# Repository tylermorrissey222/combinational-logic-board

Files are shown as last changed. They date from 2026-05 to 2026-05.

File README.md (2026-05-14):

# Combinational Logic Board

### IECE 442 — Systems Analysis & Design

**Created by Tyler Morrissey**

-----

## Overview

An educational RFID based logic gate simulator that allows
students to physically place gate tokens on RFID readers to
build and simulate combinational logic circuits in real time.

The system evaluates a 5 gate combinational circuit, displays
a live schematic with wire states, generates the Boolean
expression, and shows a truth table with the active input
row highlighted.

-----

## Hardware

### Version 1 & 1.5

- Raspberry Pi 3B — display and GPIO switches
- Arduino Mega — 5x RC522 RFID readers
- Custom PCB bus board (KiCad)
- 5x RC522 RFID readers
- 4x input switches
- Sotsu FlipAction Go 14” display

### Version 2 (in development)

- Raspberry Pi CM5 — display
- Raspberry Pi Pico 2 — RFID readers and switches
- Custom PCB with integrated Pico socket (KiCad)

-----

## Supported Gate Types

|Gate|Symbol|
|----|---|
|AND |A·B |
|OR  |A+B |
|XOR |A⊕B |
|NAND|(A·B)’|
|NOR |(A+B)’|
|XNOR|(A⊕B)’|

-----

## Features

- Real time circuit simulation
- Live truth table with active row highlight
- Boolean expression generation
- Full adder auto detection mode
- Scalable pygame display (SCALE variable)
- Arduino/Pico handles RFID over Serial to Pi

-----

## Circuit Netlist

```
Slot 1: A, B     → Gate 1 output
Slot 2: B, C     → Gate 2 output
Slot 3: G1, G2   → Gate 3 output
Slot 4: G2, D    → Gate 4 output
Slot 5: G3, G4   → Final output Y
```

-----

## Files

### Code

|File |Description |
|---|---|
|code/arduino_rfid.ino |Arduino RFID reader sketch |
|code/combinational_logic.py |Pi display script |
|code/display_test_mac.py |Mac simulation (no hardware needed)|

### PCB

|Folder |Description |
|---|---|
|pcb/v1/ |V1 bus board — Arduino to RC522 |
|pcb/v2_pico/|V2 Pico board — integrated Pico socket|

-----

## Setup

### Hardware Setup

1. Connect Arduino Mega to Pi via USB
1. Wire 5x RC522 readers to Arduino per wiring guide
1. Wire 4x switches to Pi GPIO
1. Connect display via HDMI

### Software Setup

```bash
# On Raspberry Pi
pip3 install pyserial pygame RPi.GPIO

# Run display
python3 rfid_display_arduino.py
```

### Running Mac Simulation

```bash
pip3 install pygame
python3 display_test_mac.py
```

-----

## Wiring

### Raspberry Pi — RC522 Readers

```
MOSI → GPIO10
MISO → GPIO9
SCK  → GPIO11
RST  → GPIO25
CS1  → GPIO5
CS2  → GPIO6
CS3  → GPIO13
CS4  → GPIO19
CS5  → GPIO26
```

### Arduino Mega — RC522 Readers

```
MOSI → Pin 51
MISO → Pin 50
SCK  → Pin 52
RST  → Pin 44
CS1  → Pin 38
CS2  → Pin 40
CS3  → Pin 39
CS4  → Pin 43
CS5  → Pin 49
```

### Raspberry Pi Pico 2 — RC522 Readers

```
MOSI → GPIO3
MISO → GPIO4
SCK  → GPIO2
RST  → GPIO6
CS1  → GPIO5
CS2  → GPIO9
CS3  → GPIO13
CS4  → GPIO10
CS5  → GPIO11
```

### Raspberry Pi — Input Switches

```
Switch A → GPIO17
Switch B → GPIO27
Switch C → GPIO22
Switch D → GPIO23
GND      → GND
```

### Raspberry Pi Pico 2 — Input Switches

```
GP0  → UART TX (to Pi 5 RX when using direct UART)
GP1  → UART RX (to Pi 5 TX when using direct UART)
GP15 → Reset button
GP16 → Reset (reassigned to clock later)
GP18 → SW_C
GP19 → SW_B
GP20 → SW_A
GP22 → SW_D
```

-----

## Gate Token UIDs

Add your RFID tag UIDs to the Arduino sketch getGate() function:

```cpp
if (uid == "YOUR_UID") return "AND";
```

Scan unknown tags with the Arduino — UIDs print to Serial Monitor.

-----

## License

MIT License — free to use and modify

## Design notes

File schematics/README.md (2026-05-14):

# 2D Engineering Drawings and Schematics
This directory provides the following 2D schematics and Engineering Drawings
* Circuit (v1, v1.5, v2)
* RFID Gate Tags
* Full Model Casing Unit

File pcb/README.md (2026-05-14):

# PCB Design & Production Files

This directory provides the PCB Board Design and production files as well as some of the component files (Pico 2).

## Version 1 (v1)
Original design with the Arduino Mega & Raspberry Pi 3B.
* RFID_BOARD.zip
---
## Version 2 (v2)
Replaced Arduino with Pico 2 for the microcontroller and added to the PCB.
* LogicBoardV2_2.zip

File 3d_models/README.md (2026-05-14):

# 3D Models 
This directory provides the 3D models / step files for printing

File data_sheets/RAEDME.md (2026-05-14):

# Datasheets
Here you will find the data sheets for all the components needed for each version of the project.
The following components have been provided:
* Raspberry Pi 3B
* Raspberry Pi Pico 2
* Raspberry Pi CM5
* Raspberry Pi CM5 IO Board
* Arduino Mega
* RC522 RFID Reader

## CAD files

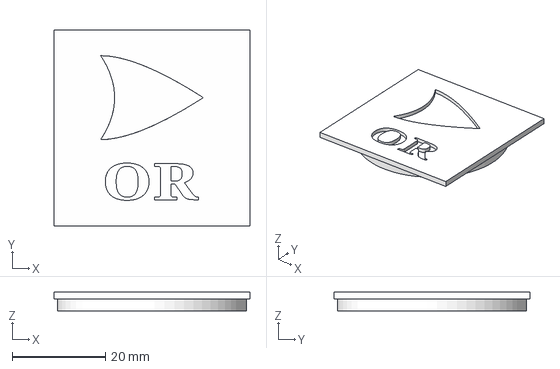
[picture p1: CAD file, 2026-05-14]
3d_models/OR.step
42.0 x 42.0 x 4.00 mm

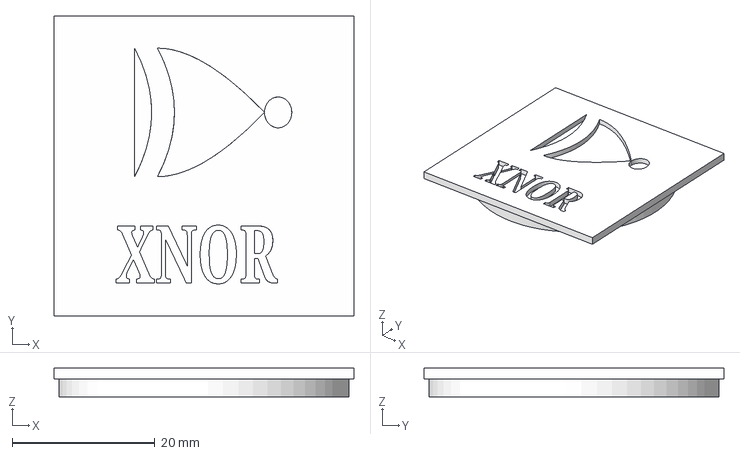
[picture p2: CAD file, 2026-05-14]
3d_models/XNOR.step
42.0 x 42.0 x 4.00 mm

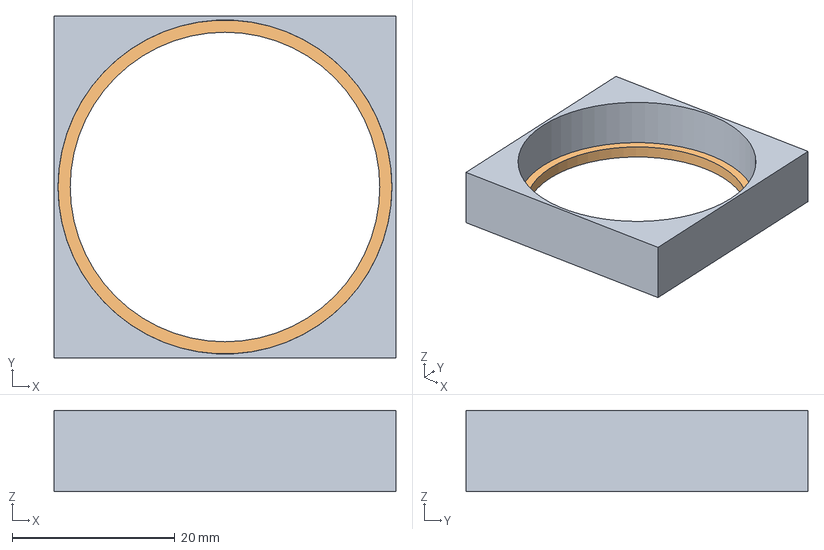
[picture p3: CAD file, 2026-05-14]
3d_models/GATE BOTTOM.step
42.0 x 42.0 x 10.00 mm

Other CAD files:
3d_models/NOR.step
3d_models/XOR.step
3d_models/NAND.step
3d_models/AND.step

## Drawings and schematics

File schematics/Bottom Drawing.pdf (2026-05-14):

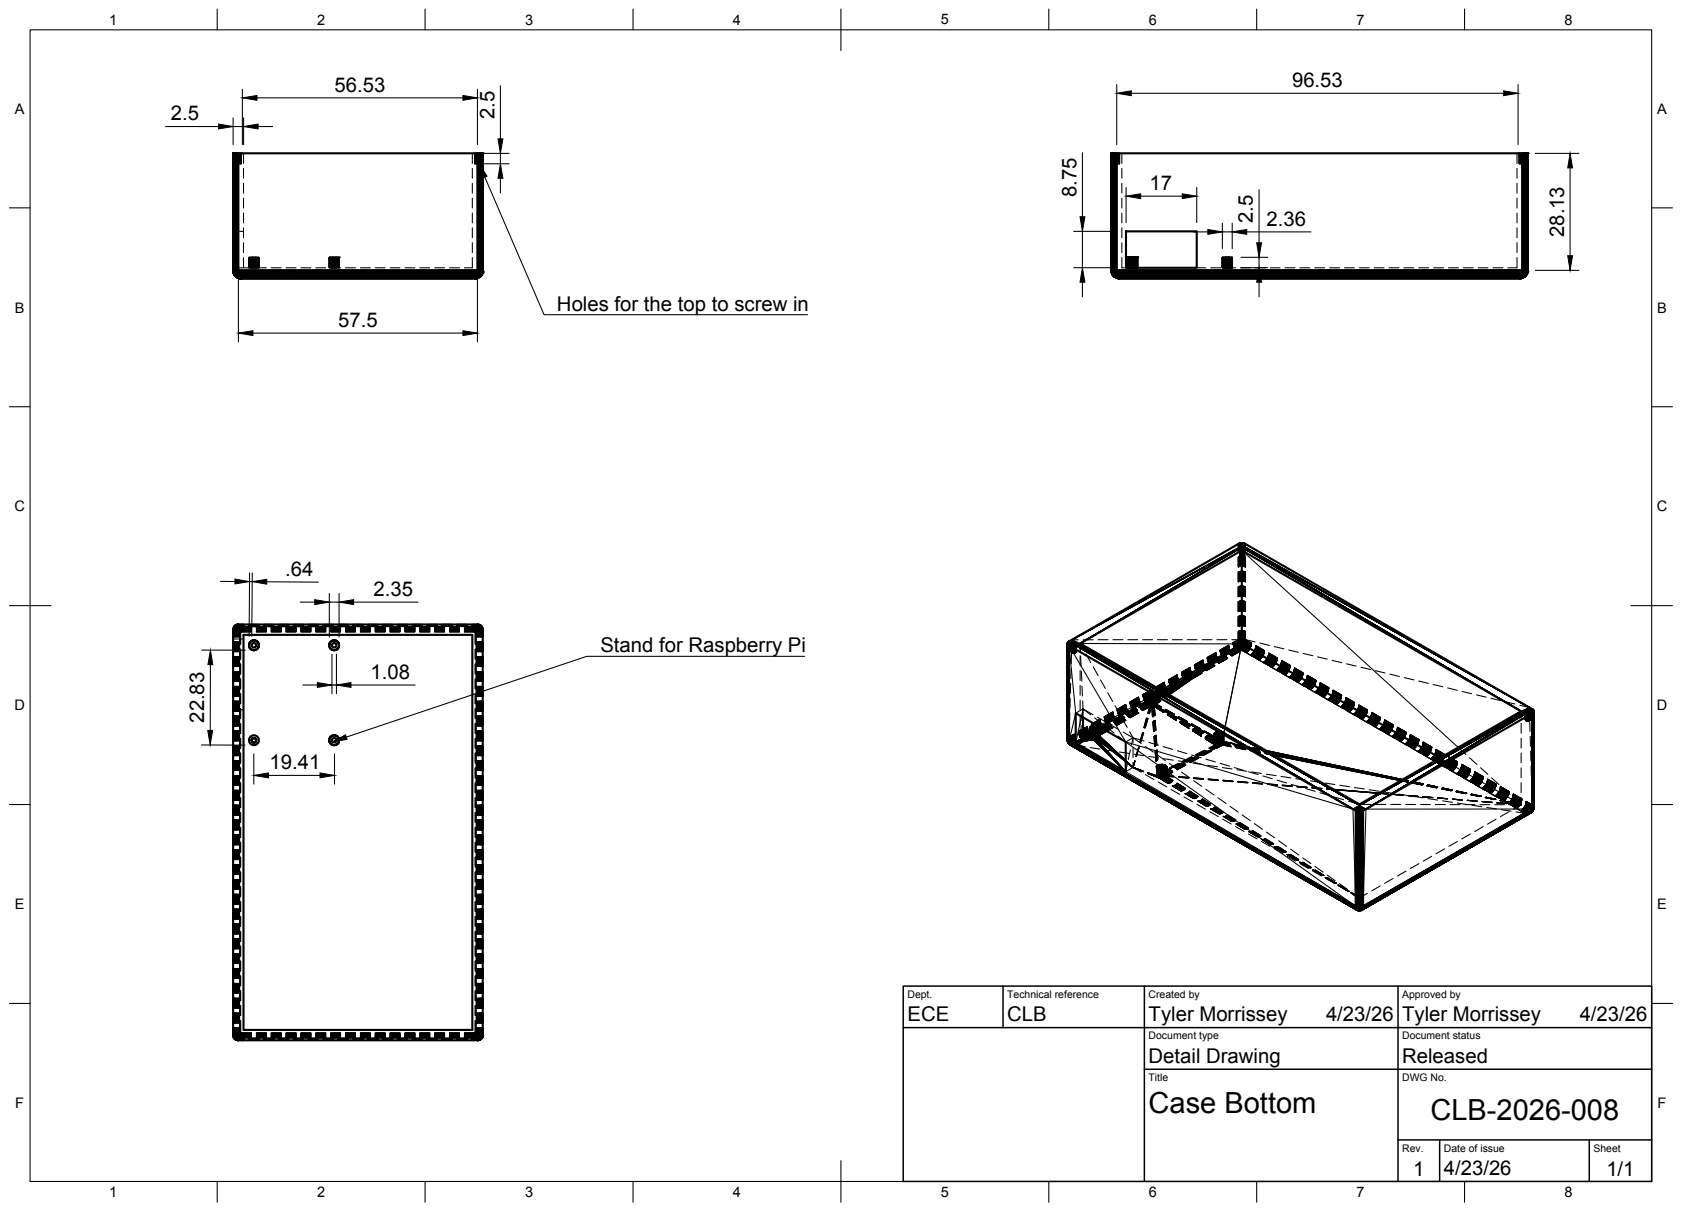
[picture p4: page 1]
Dept.; Technical reference; Created by; Approved by; Document type; Document status; Title; DWG No.; Rev.; Date of issue; Sheet; Detail Drawing; Released; Case Bottom; CLB-2026-008; ECE; CLB; Tyler Morrissey; Tyler Morrissey 2.5 2.36

Holes for the top to screw in

Stand for Raspberry Pi

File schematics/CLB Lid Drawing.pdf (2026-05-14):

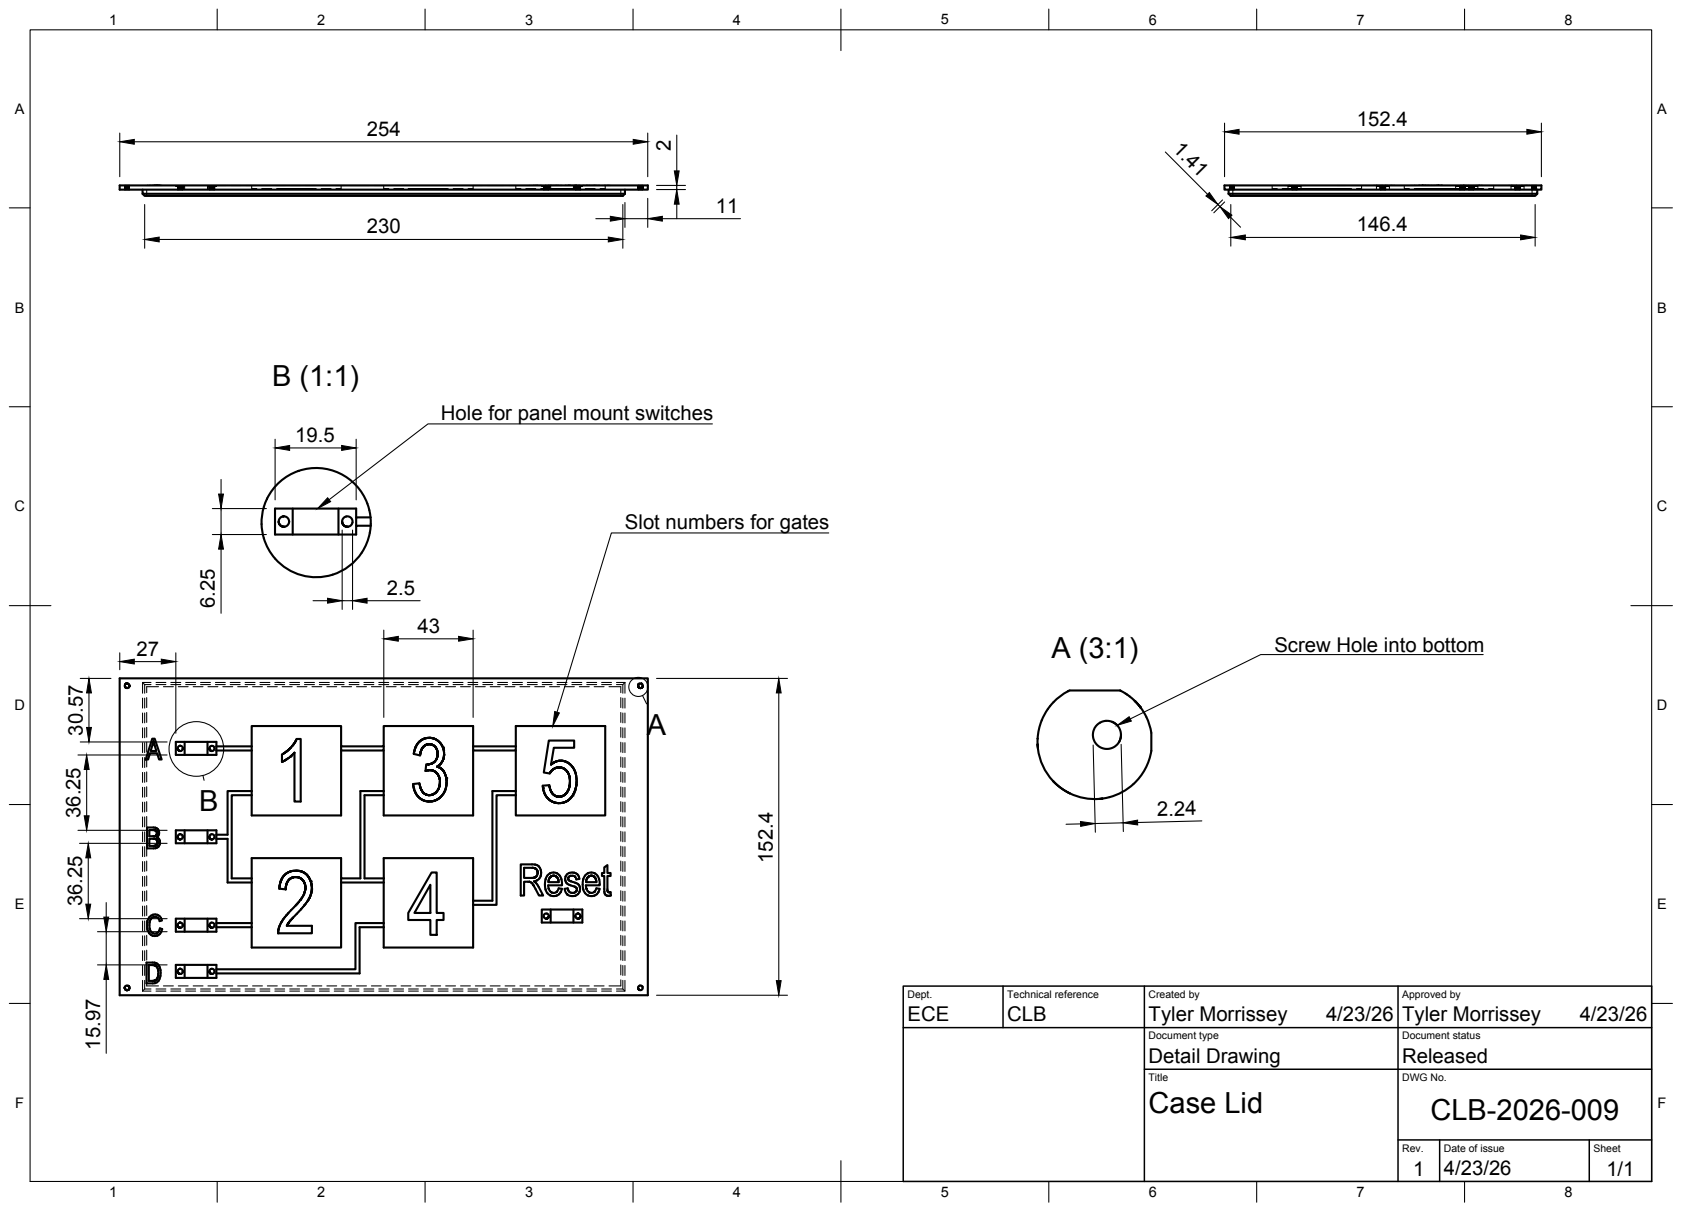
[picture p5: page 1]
Dept.; Technical reference; Created by; Approved by; Document type; Document status; Title; DWG No.; Rev.; Date of issue; Sheet; Detail Drawing; Released; Case Lid; CLB-2026-009; ECE; CLB; Tyler Morrissey

Hole for panel mount switches

Slot numbers for gates

Screw Hole into bottom

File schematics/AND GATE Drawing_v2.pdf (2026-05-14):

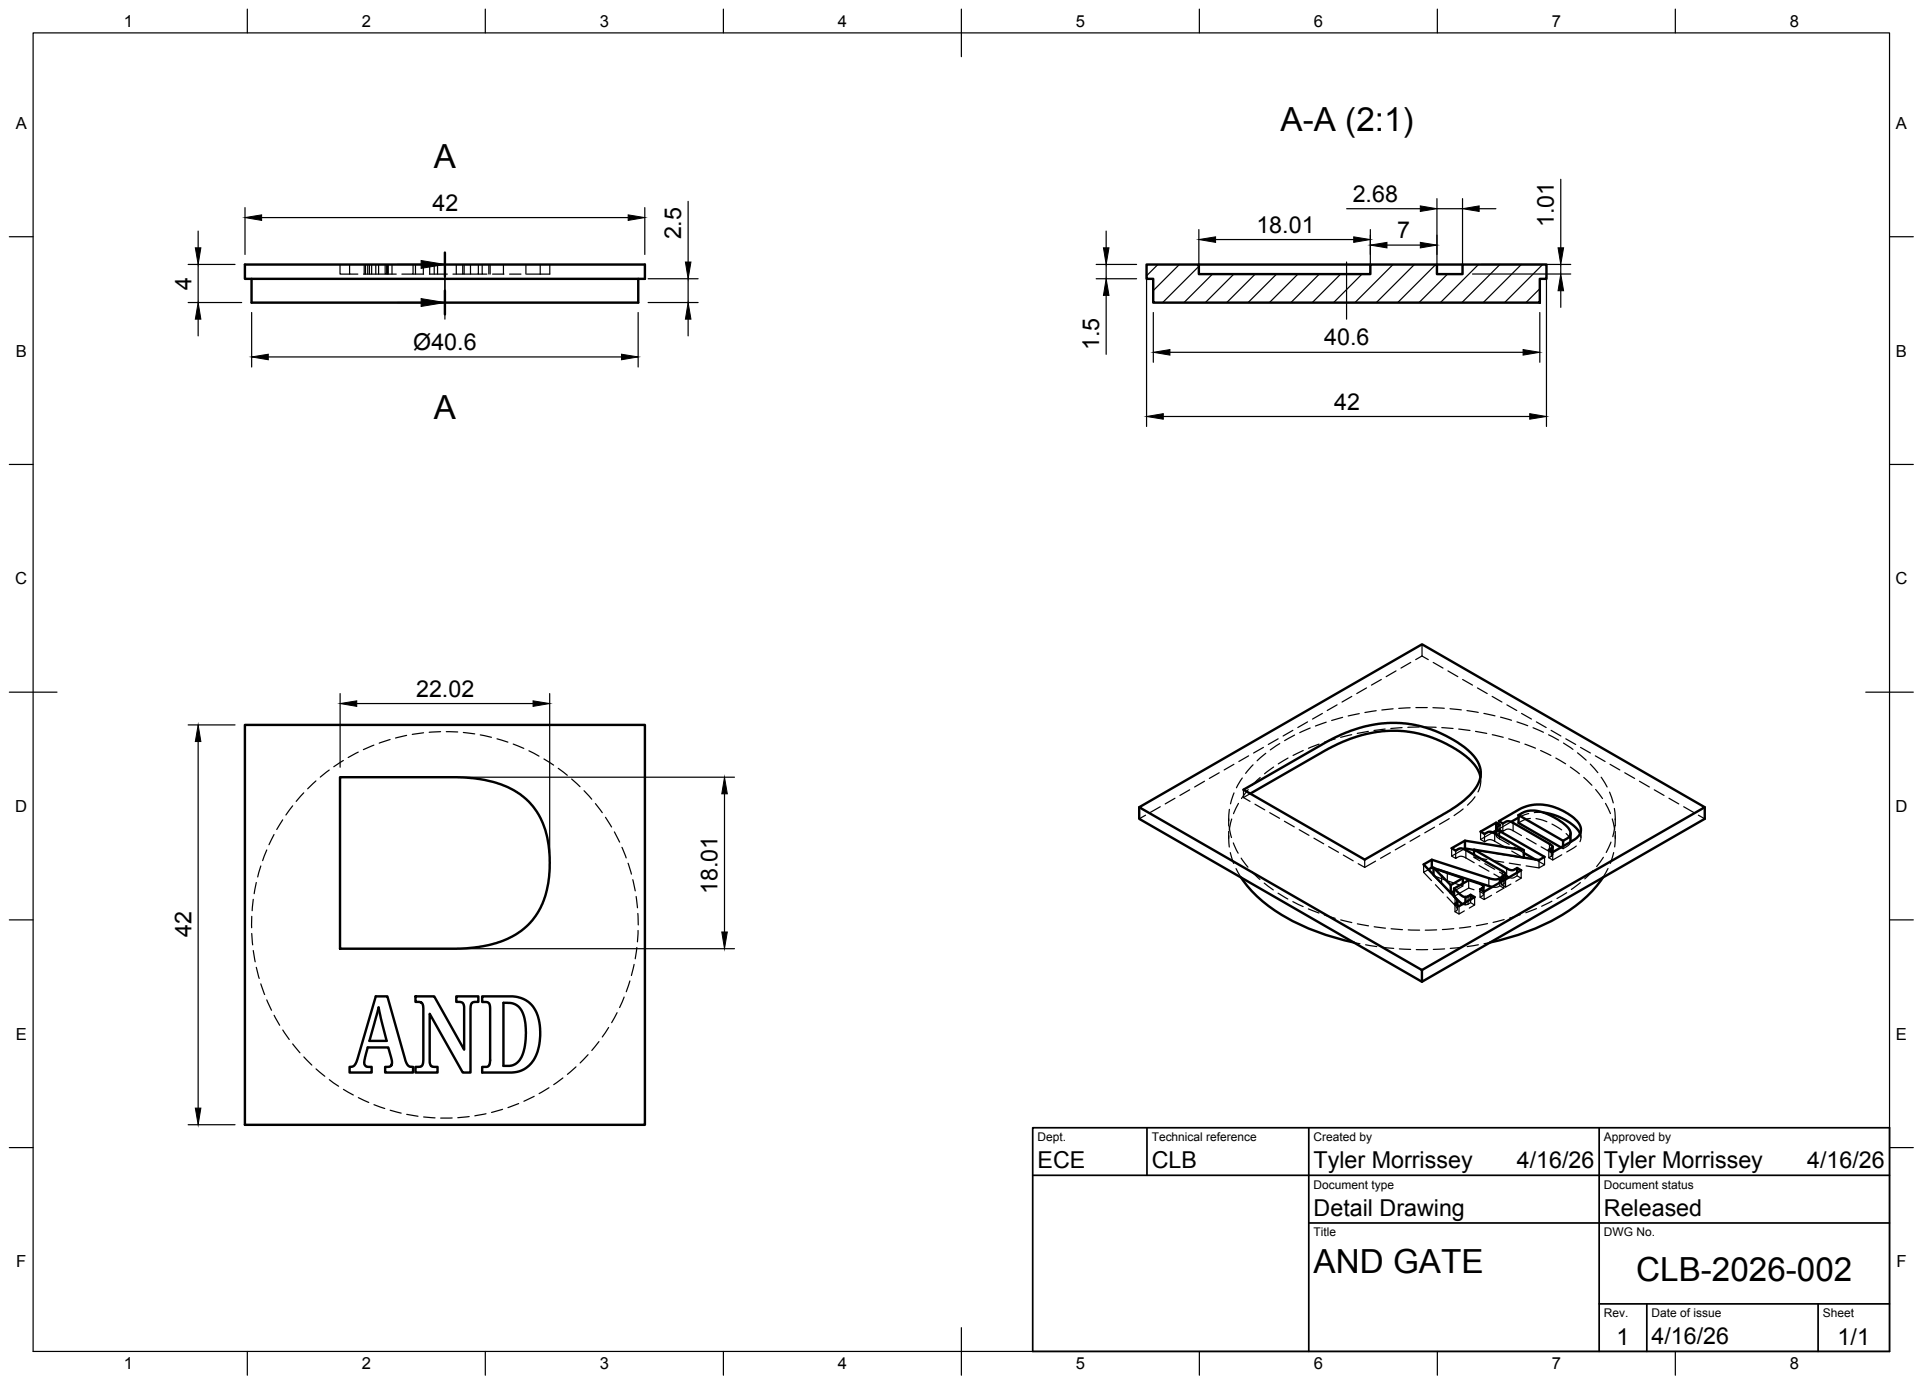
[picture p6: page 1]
Title; DWG No.; Rev.; Date of issue; Sheet; AND GATE; CLB-2026-002

Dept. ECE | Technical reference CLB | Created by Tyler Morrissey 4/16/26 | Approved by Tyler Morrissey 4/16/26

Document type Detail Drawing | Document status Released

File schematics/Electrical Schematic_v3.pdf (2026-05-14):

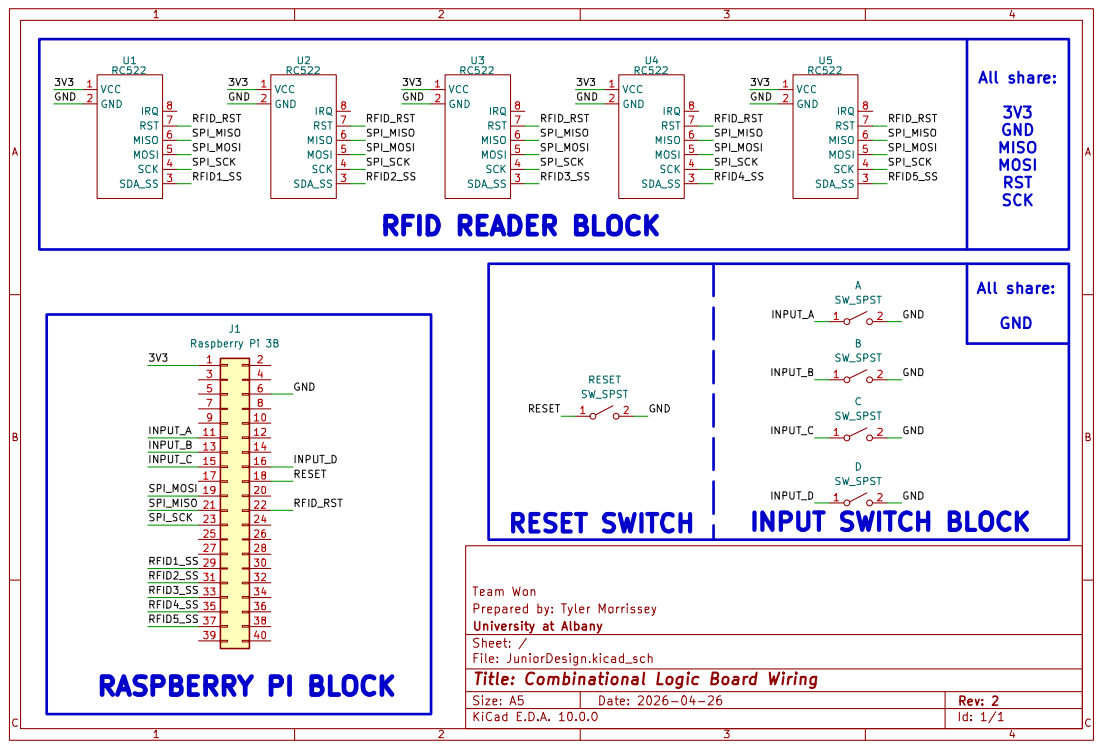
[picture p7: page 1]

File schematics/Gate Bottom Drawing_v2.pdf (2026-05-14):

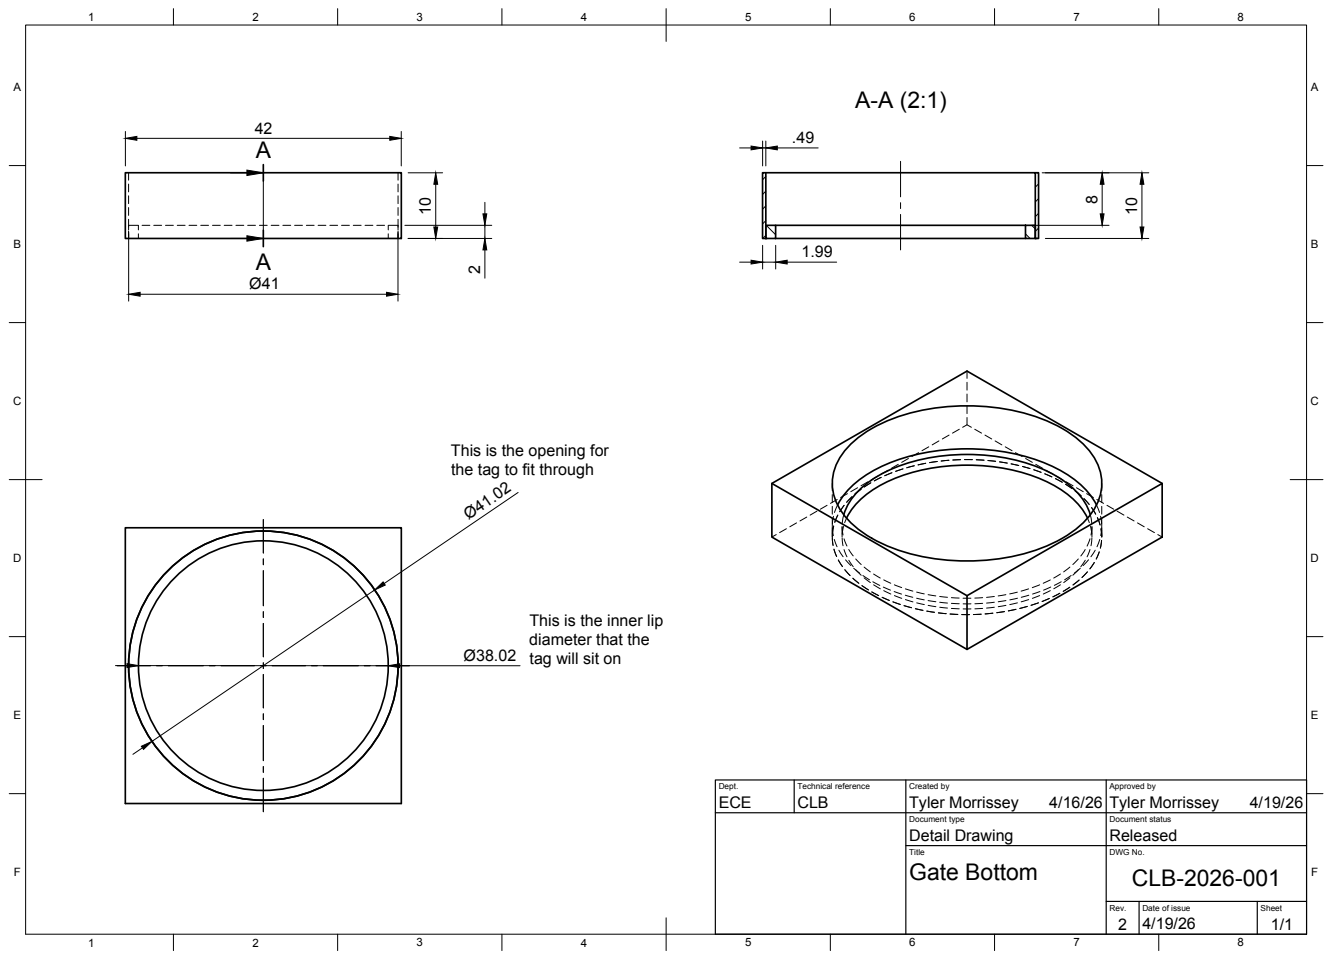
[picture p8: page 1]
Title; DWG No.; Rev.; Date of issue; Sheet; Gate Bottom; CLB-2026-001

This is the opening for
the tag to fit through

This is the inner lip
diameter that the
tag will sit on

Dept. ECE | Technical reference CLB | Created by Tyler Morrissey 4/16/26 | Approved by Tyler Morrissey 4/19/26

Document type Detail Drawing | Document status Released

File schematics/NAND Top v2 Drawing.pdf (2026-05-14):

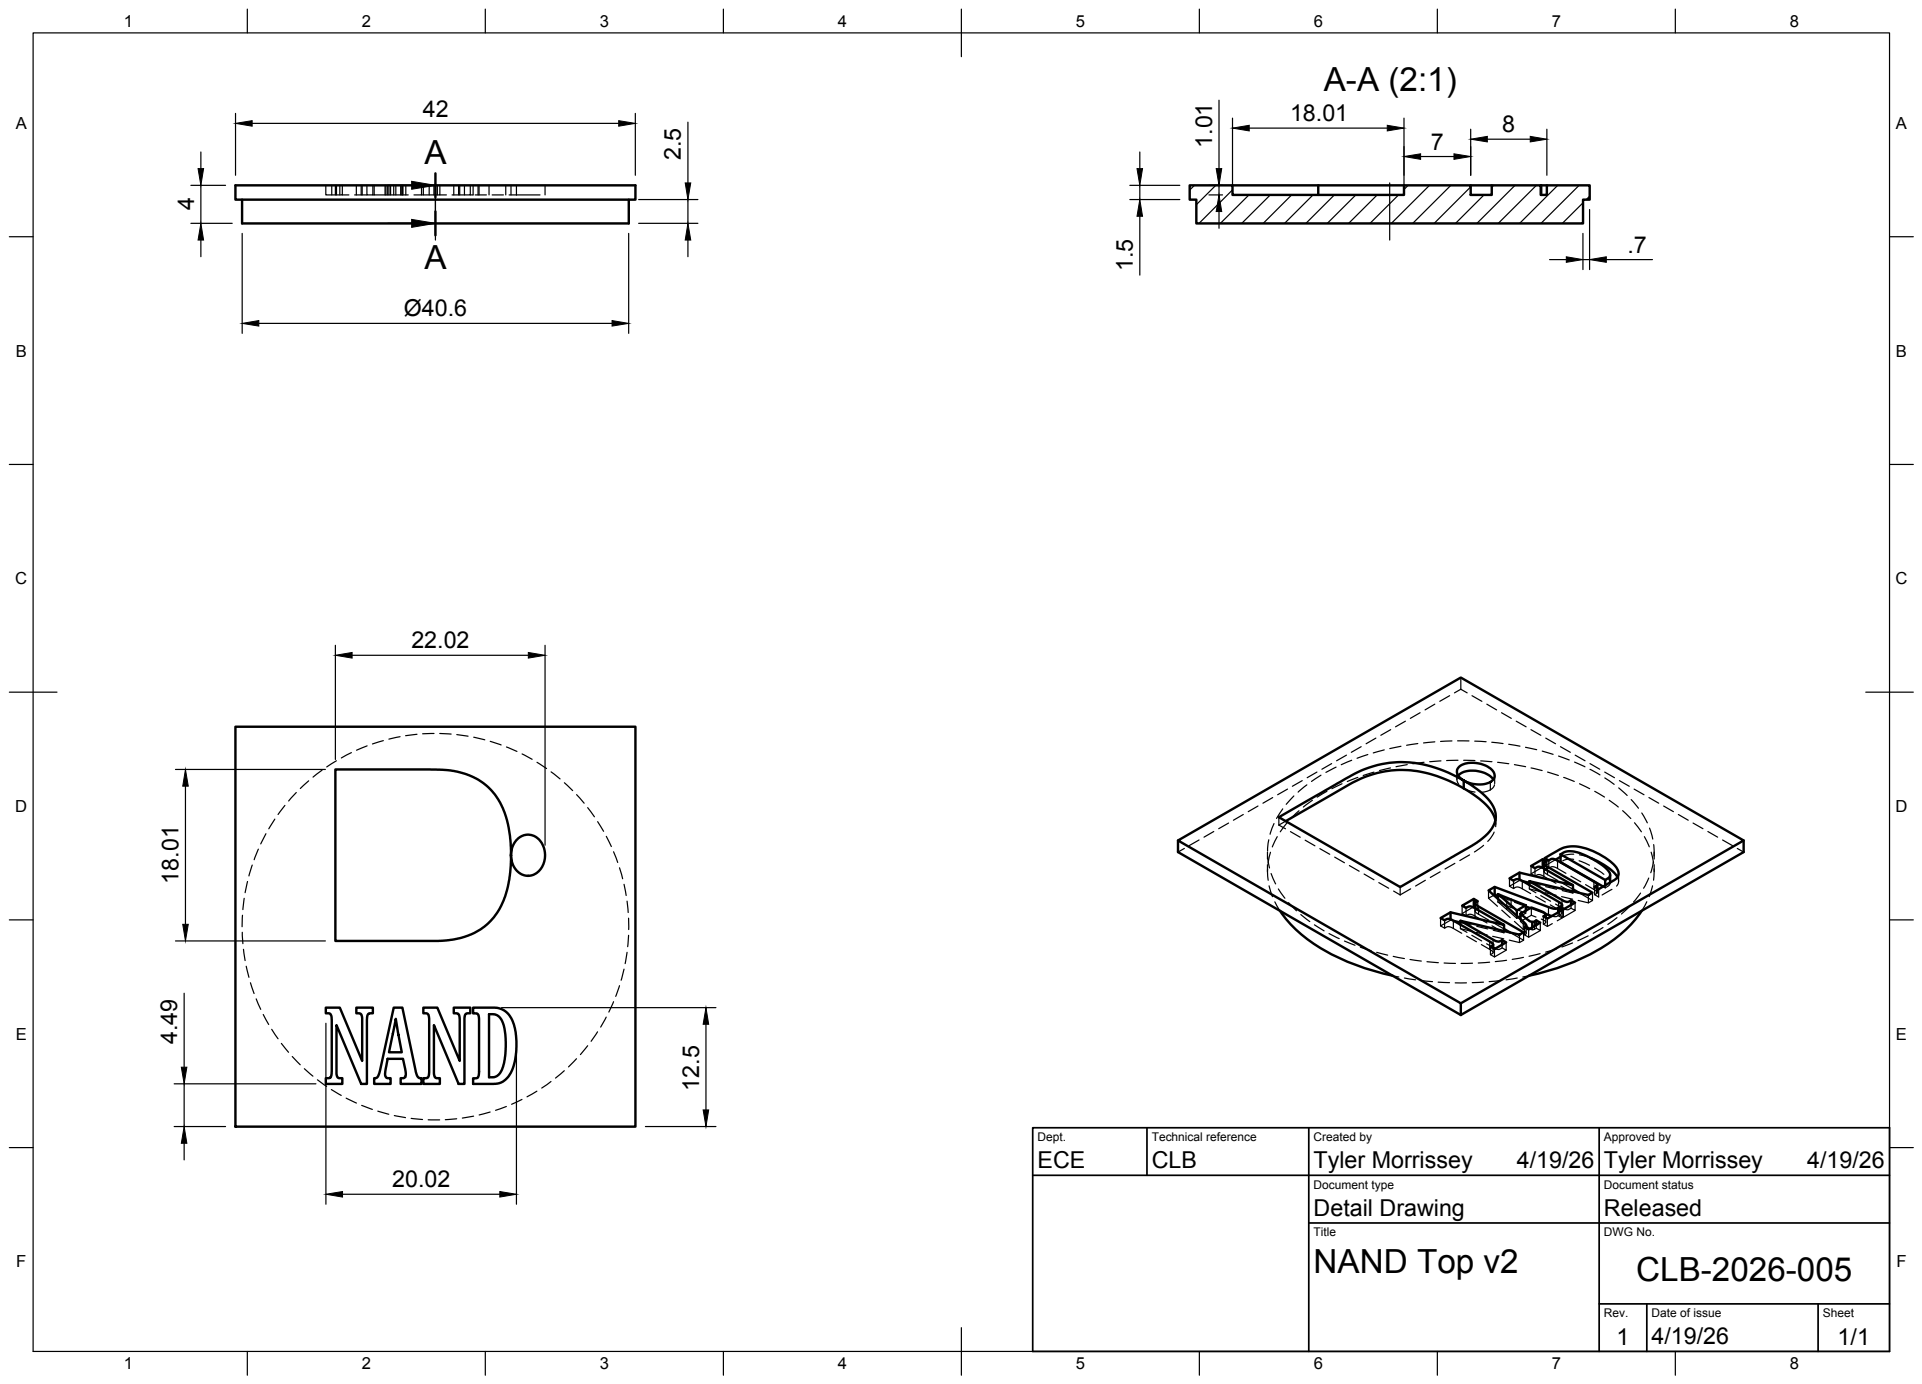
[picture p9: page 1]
Title; DWG No.; Rev.; Date of issue; Sheet; NAND Top v2; CLB-2026-005

Dept. ECE | Technical reference CLB | Created by Tyler Morrissey 4/19/26 | Approved by Tyler Morrissey 4/19/26

Document type Detail Drawing | Document status Released

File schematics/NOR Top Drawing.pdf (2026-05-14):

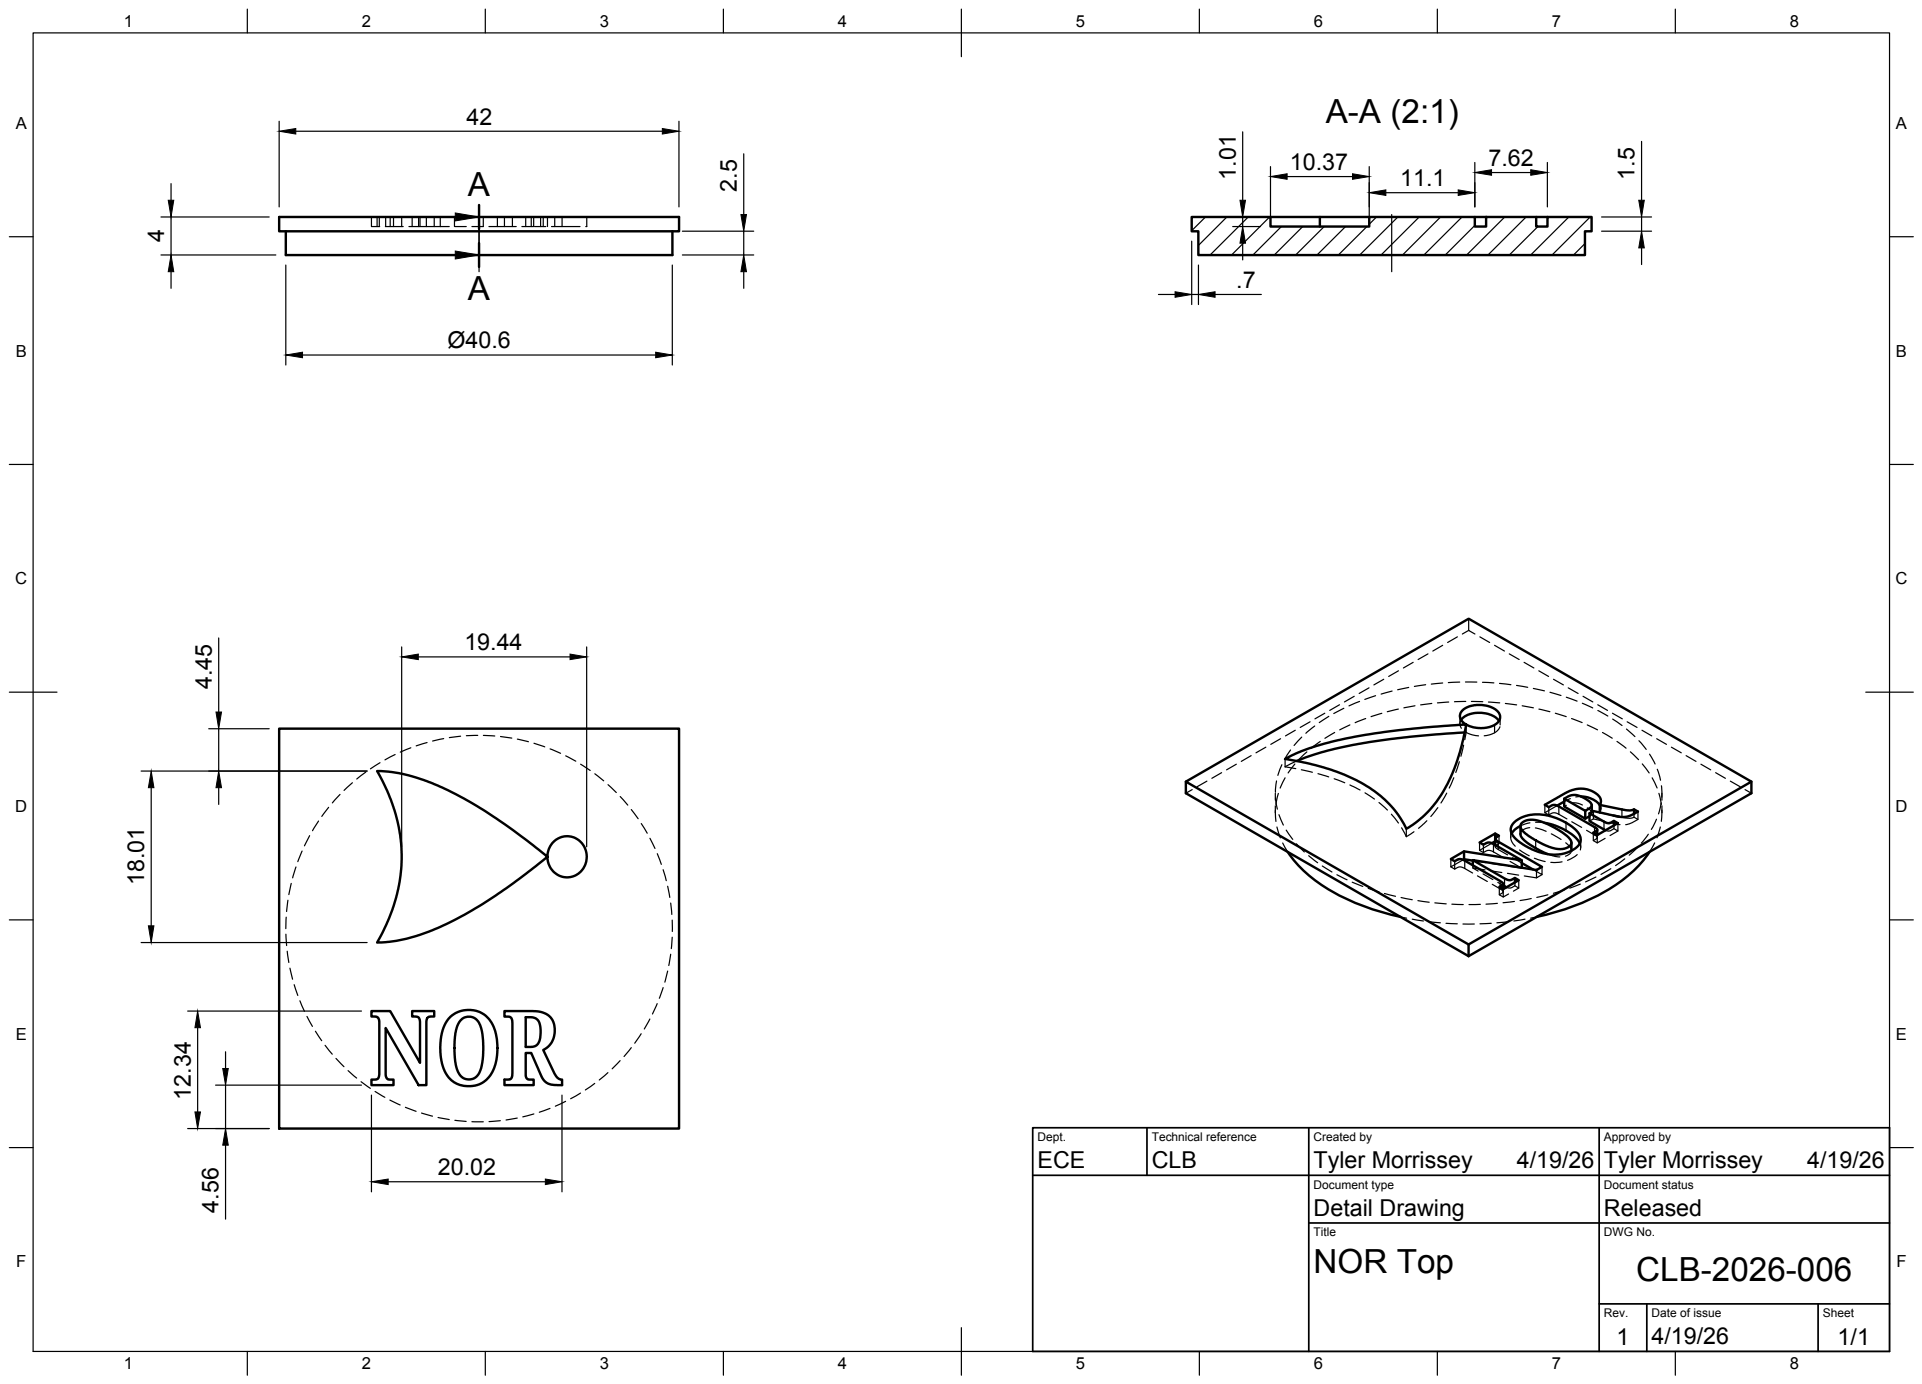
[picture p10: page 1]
Title; DWG No.; Rev.; Date of issue; Sheet; NOR Top; CLB-2026-006

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

Document type Detail Drawing | Document status Released

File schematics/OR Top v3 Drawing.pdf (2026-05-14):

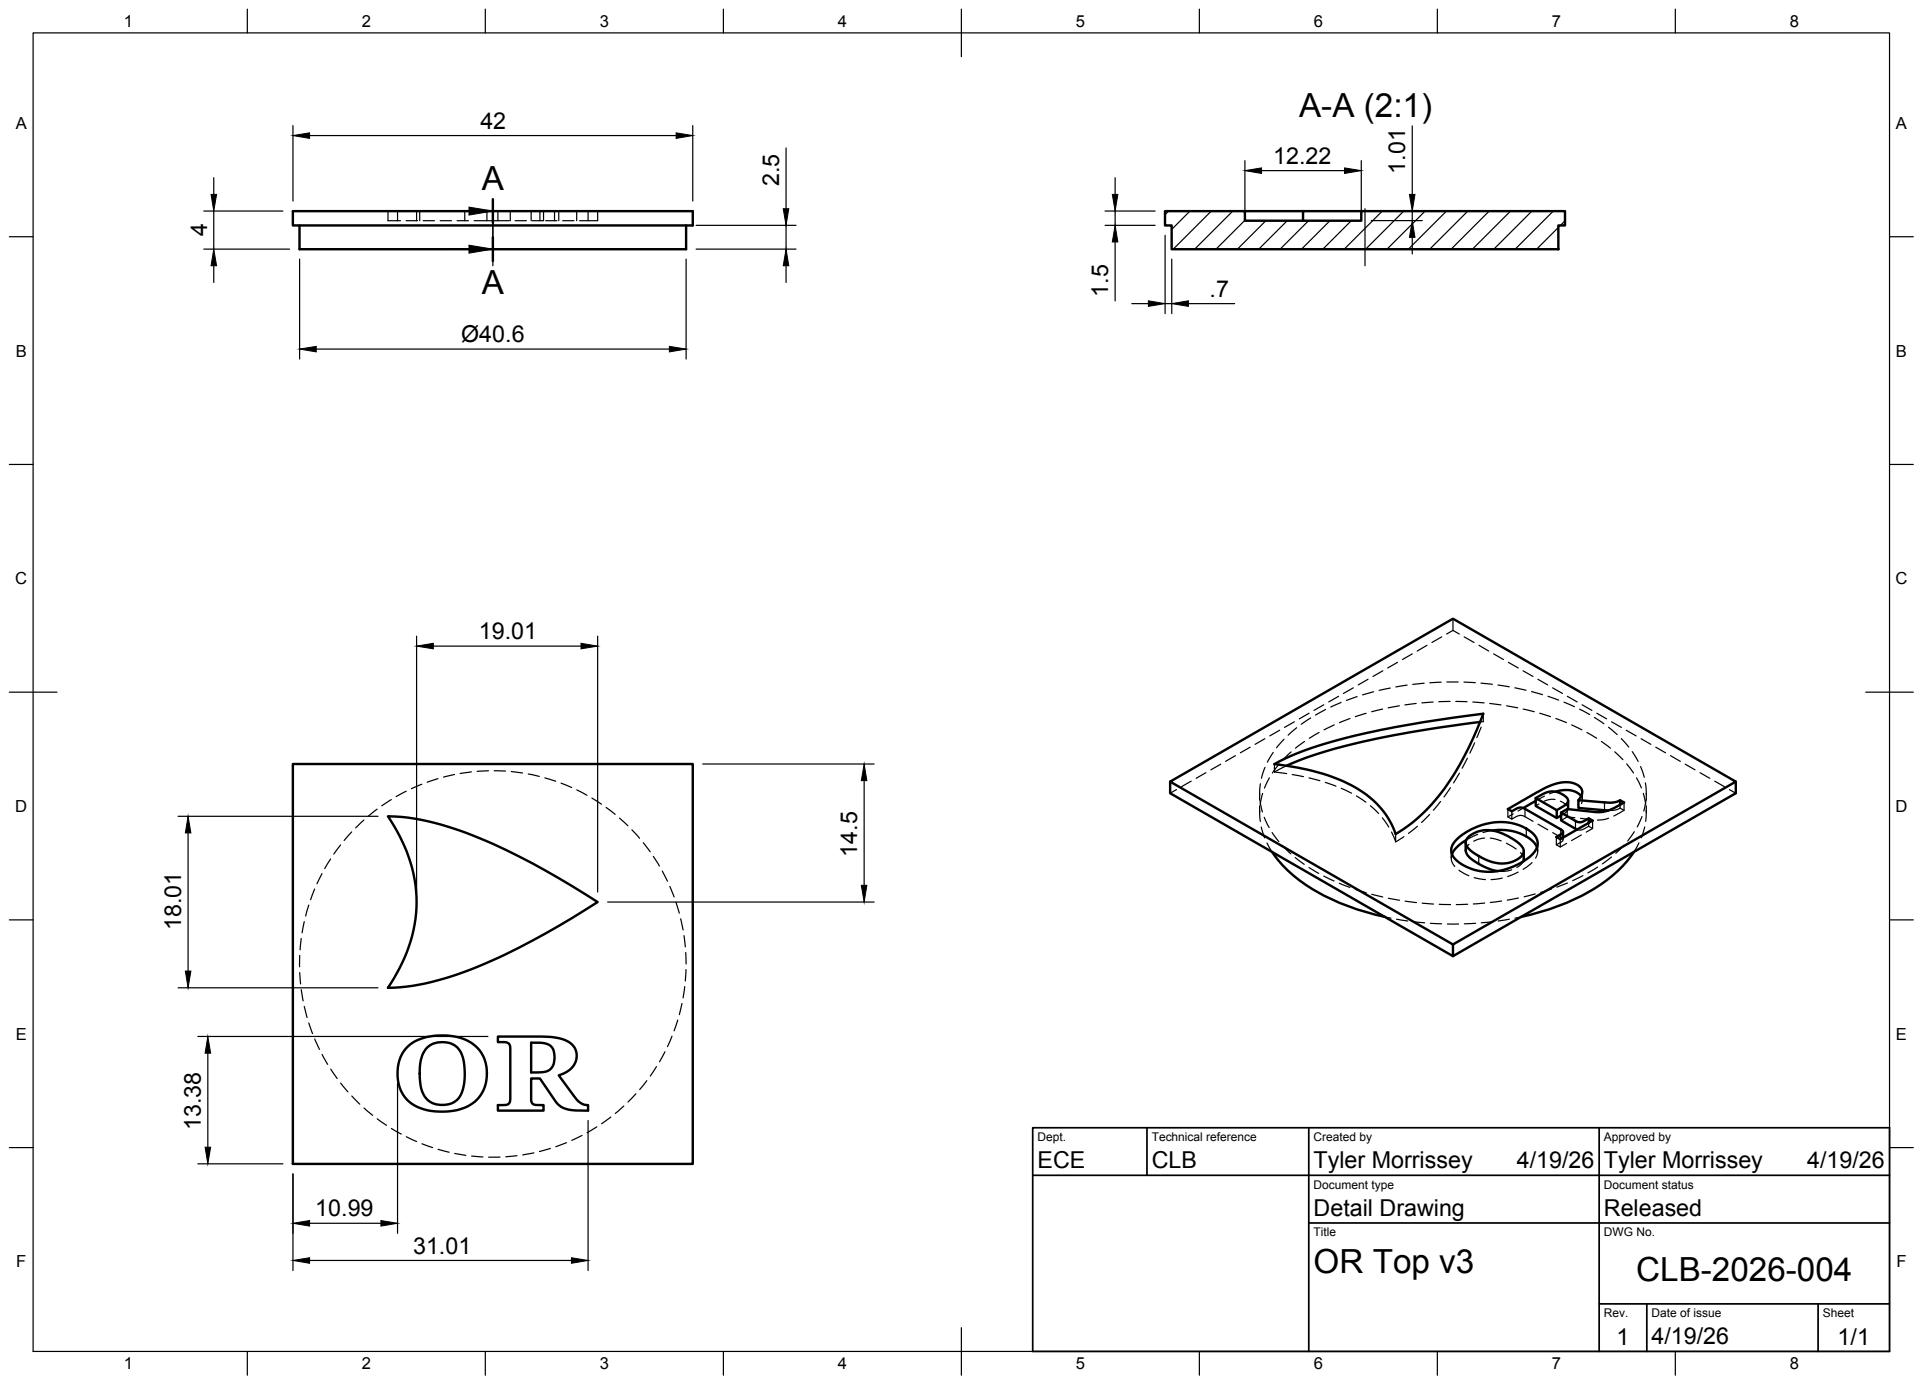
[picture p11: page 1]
Title; DWG No.; Rev.; Date of issue; Sheet; OR Top v3; CLB-2026-004

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

Document type Detail Drawing | Document status Released

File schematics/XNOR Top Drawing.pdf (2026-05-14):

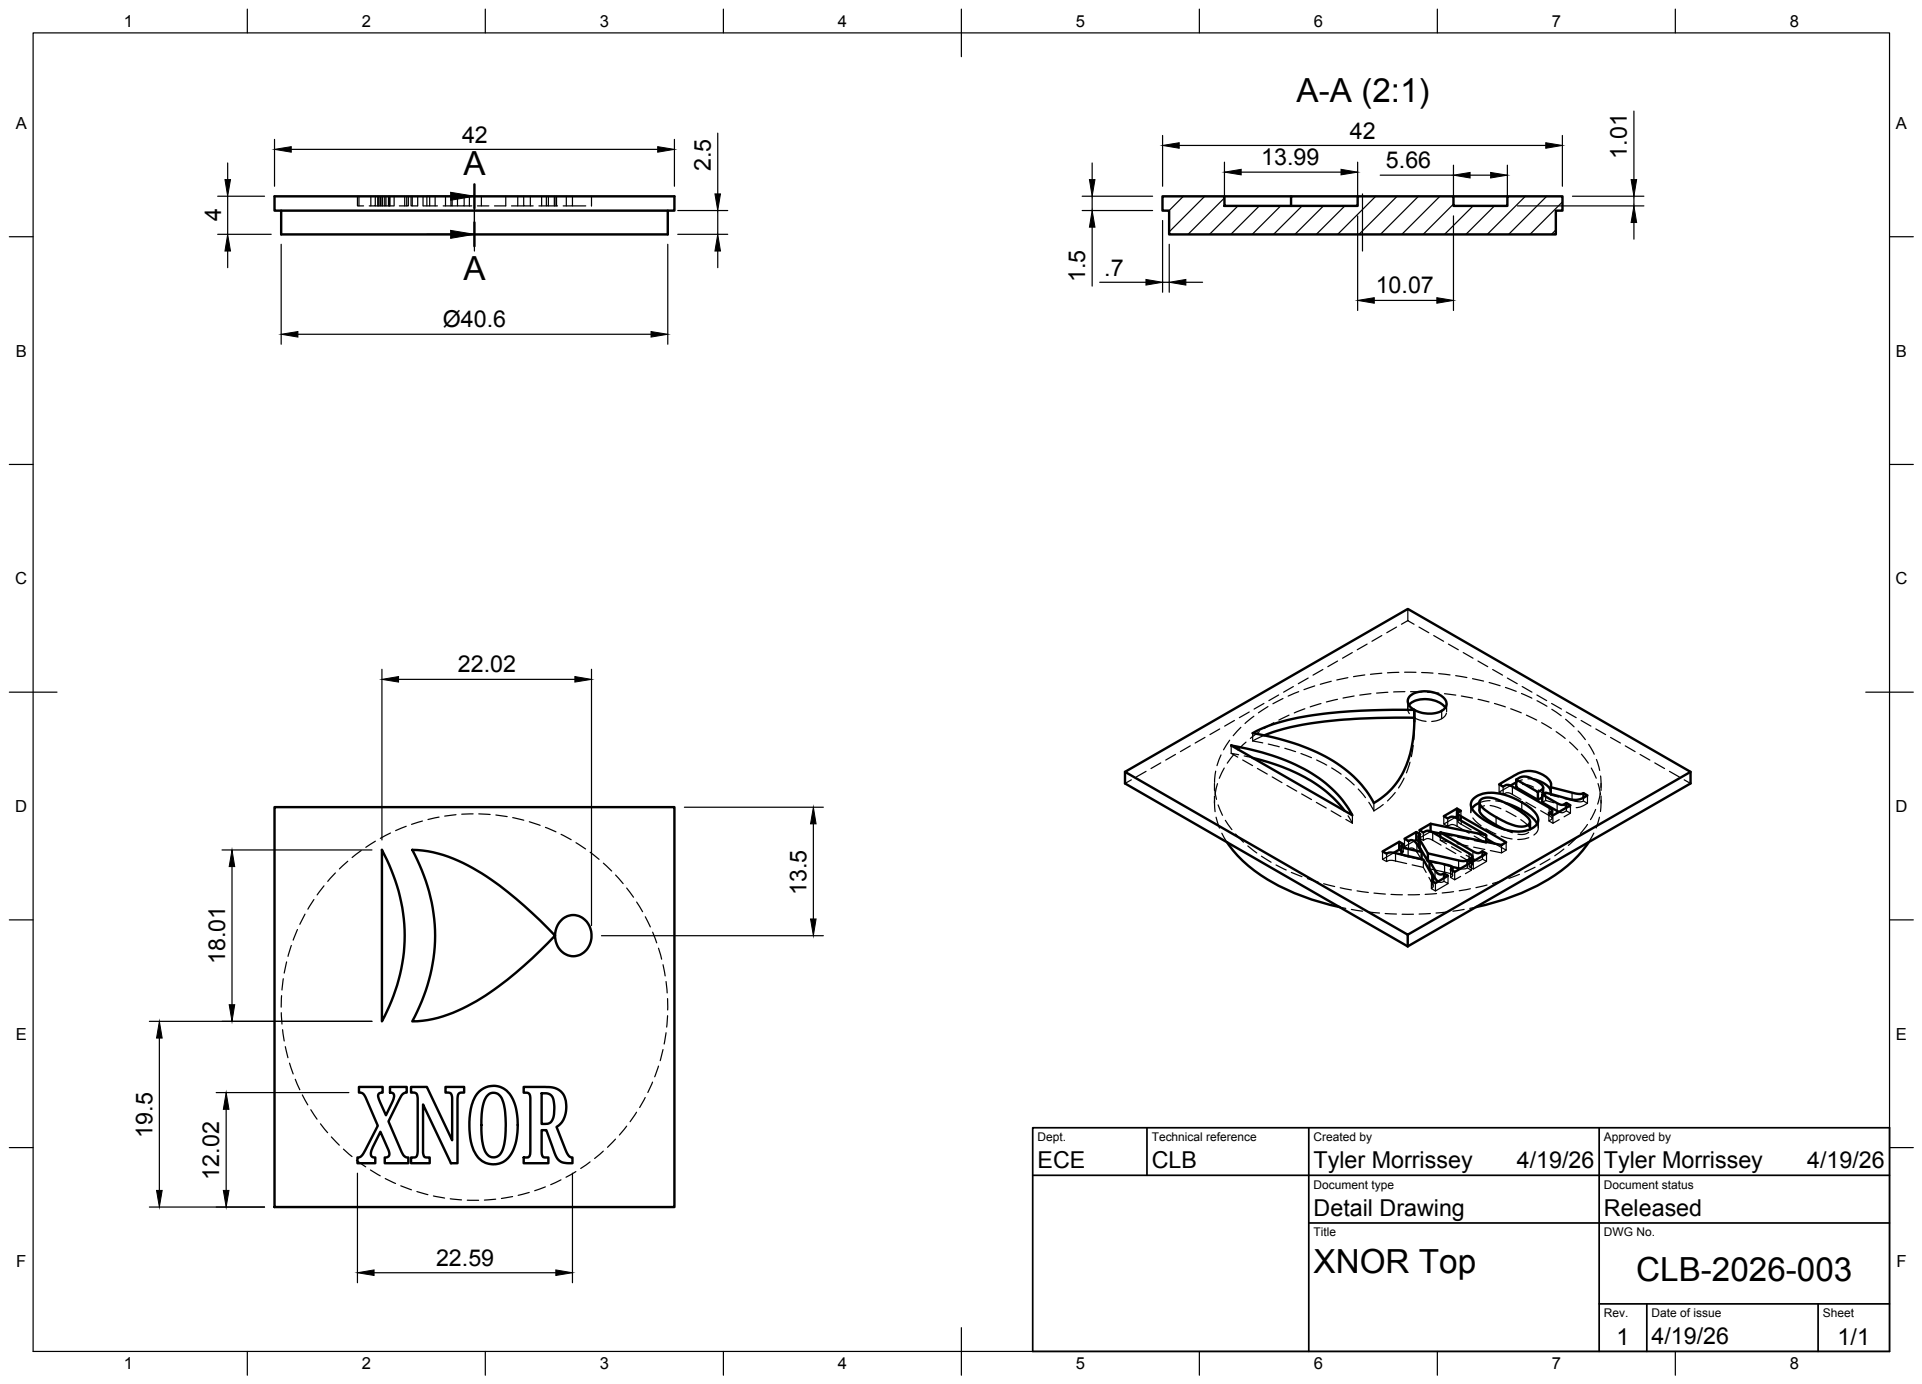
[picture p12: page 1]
Title; DWG No.; Rev.; Date of issue; Sheet; XNOR Top; CLB-2026-003

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

Document type Detail Drawing | Document status Released

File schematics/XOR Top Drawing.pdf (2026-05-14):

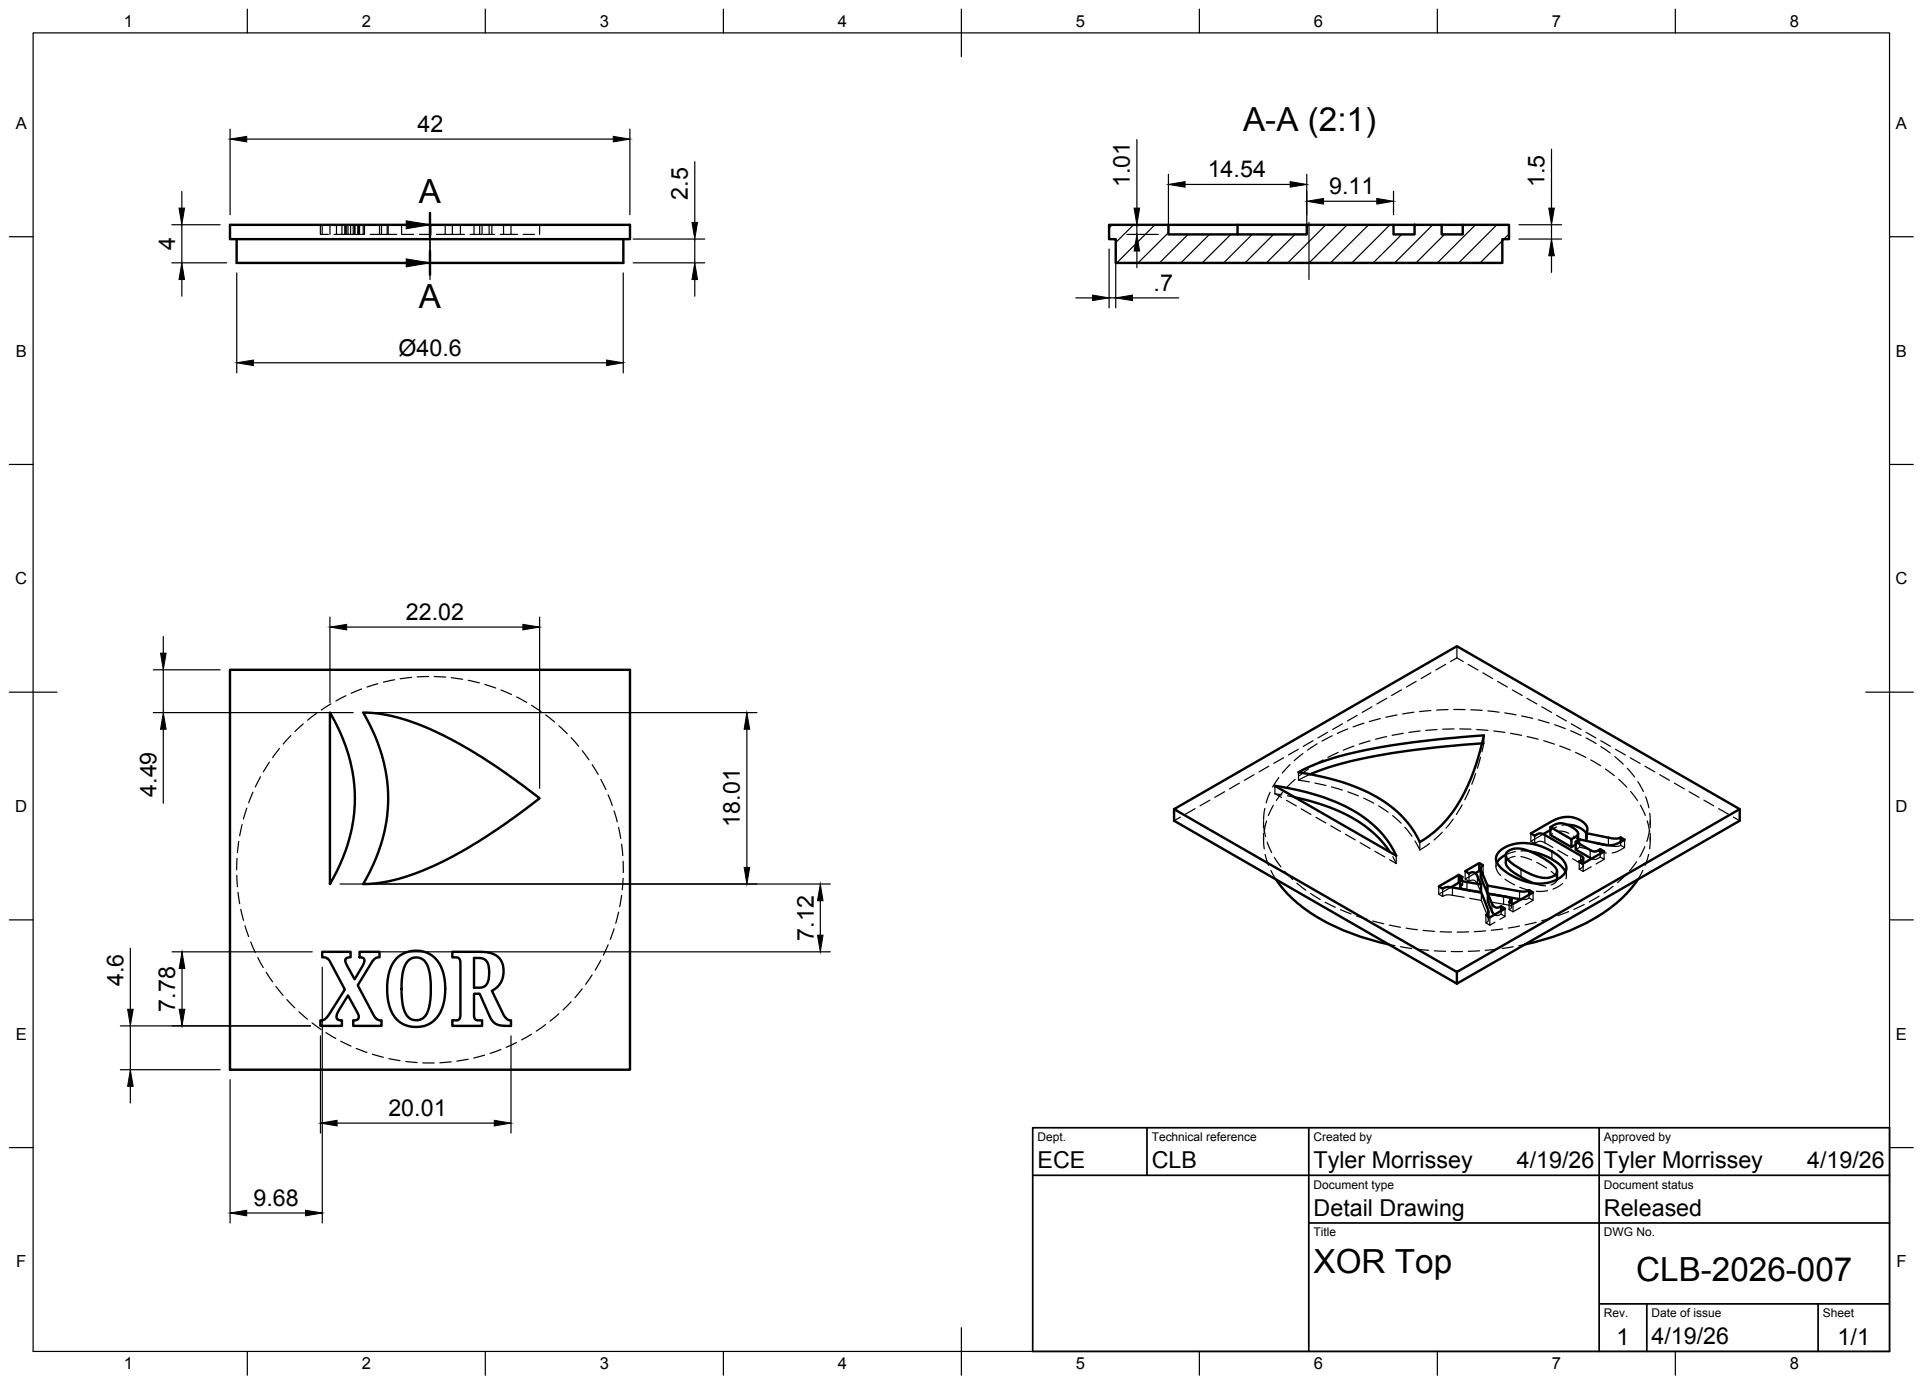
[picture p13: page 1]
Title; DWG No.; Rev.; Date of issue; Sheet; XOR Top; CLB-2026-007

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

Document type Detail Drawing | Document status Released

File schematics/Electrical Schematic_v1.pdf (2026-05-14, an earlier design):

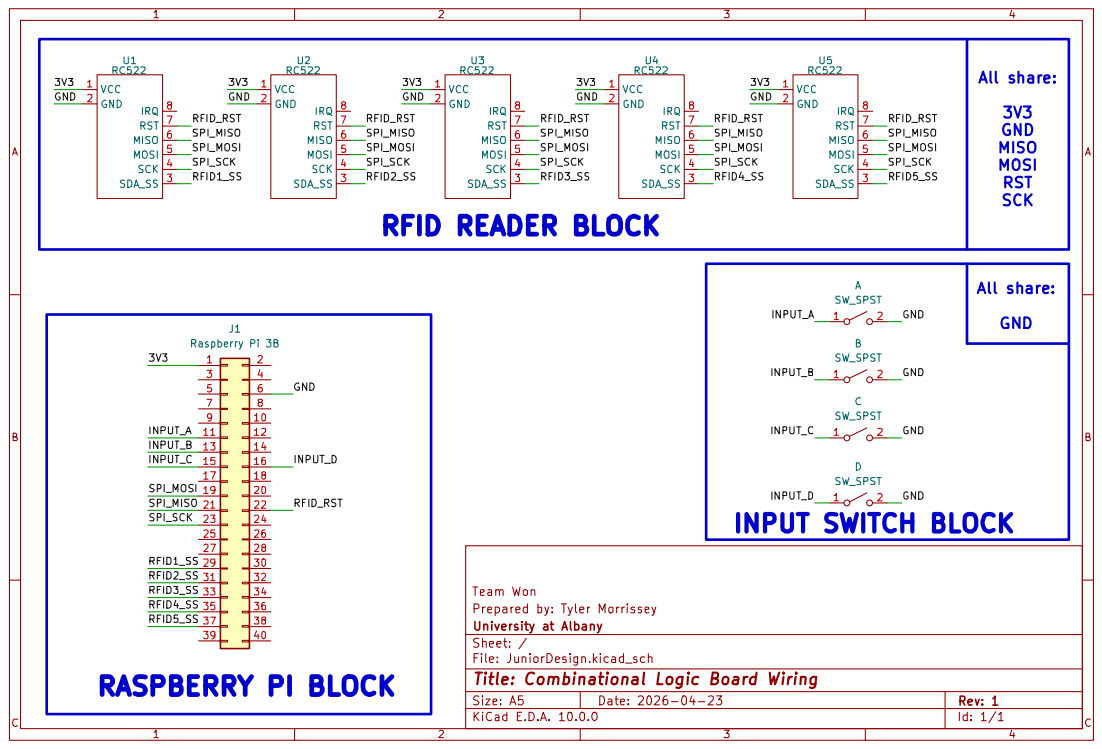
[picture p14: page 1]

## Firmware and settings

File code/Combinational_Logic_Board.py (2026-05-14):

import threading
import time
import itertools
import os
import pygame
from mfrc522 import SimpleMFRC522
import RPi.GPIO as GPIO

"""
RFID LOGIC GATE SYSTEM & DISPLAY — 5 Readers (FULL VERSION)

Project Name: Combinational Logic Board
Team Name: Team Won
Team Members: Tyler Morrissey, Dillon O'Brien, Kemarli Thomas

This file is the software architecture implementation for the Combinational Logic Board,
which was originally developed by Tyler Morrissey, a member of Team Won for the Junior Design Project (IECE442). 

We Reserve ALL rights and ownership of this file & its contents, which includes (and not limited) to:
    Functions
    Algorithms
    Classes

The following description outlines the wiring requirements for the RFIDs and Input Switches.

Wiring:
   Reader 1 SDA -> GPIO8  (CE0)
   Reader 2 SDA -> GPIO7  (CE1)
   Reader 3 SDA -> GPIO5
   Reader 4 SDA -> GPIO6
   Reader 5 SDA -> GPIO13

   All readers share: SCK->GPIO11, MOSI->GPIO10, MISO->GPIO9, RST->GPIO25
   
Switches:
   Switch A -> GPIO17, B -> GPIO27, C -> GPIO22, D -> GPIO23, RESET -> GPIO24
   All switches: one leg to GPIO pin, other leg to GND
"""
# Gate UIDs
rfid_gate_map = {
    879477249: "AND",
    3400733702: "AND",
    1193549219: "AND",
    3886782882: "OR",
    2766602469: "OR",
    437713121: "OR",
    656317444: "XOR",
    3877124002: "XOR",
    3840998373: "NAND",
    3348239266: "NAND",
    3882661026: "XNOR",
    1721176838: "XNOR",
    3883018402: "NOR",
    92351519: "NOR",
}

NUM_SLOTS   = 5
INPUT_NAMES = ["A", "B", "C", "D"]
RESET_PIN = 24

# CS pin for each reader slot
CS_PINS     = [8, 7, 5, 6, 13]

# Switch GPIO pins
INPUT_PINS  = [17, 27, 22, 23]   # A, B, C, D

# GATE LOGIC

def evaluate_gate(gate_type, a, b=0):
    """
    This Function describes the logic of each gate that we defined.

    :param gate_type:
    :param a:
    :param b:
    :return:
    """
    if gate_type == "AND":  return a & b
    if gate_type == "OR":   return a | b
    if gate_type == "XOR":  return a ^ b
    if gate_type == "NAND": return 1 - (a & b)
    if gate_type == "NOR":  return 1 - (a | b)
    if gate_type == "NOT":  return 1 - a
    if gate_type == "XNOR": return 1 - (a ^ b)
    return 0


def eval_circuit(slots, inputs):
    """
    Netlist:
      Slot 0: A, B
      Slot 1: B, C
      Slot 2: S0_out, S1_out
      Slot 3: S1_out, D
      Slot 4: S2_out, S3_out -> OUT
    """
    a, b, c, d = inputs
    out0 = evaluate_gate(slots[0], a, b)
    out1 = evaluate_gate(slots[1], b, c)
    out2 = evaluate_gate(slots[2], out0, out1)
    out3 = evaluate_gate(slots[3], out1, d)
    out4 = evaluate_gate(slots[4], out2, out3)
    return out0, out1, out2, out3, out4


def get_truth_table(slots):
    """
    This function builds a truth table from the input slots.
    :param slots:
    :return:
    """
    results = []
    for bits in itertools.product((0, 1), repeat=4):
        _, _, _, _, final = eval_circuit(slots, bits)
        results.append((*bits, final))
    return results


def build_boolean_expr(slots):
    """
    This function builds a boolean expression from the input slots.
    :param slots:
    :return:
    """
    def sym(gate, a, b=None):
        if gate == "AND":   return f"({a}\u00b7{b})"
        if gate == "OR":    return f"({a}+{b})"
        if gate == "XOR":   return f"({a}\u2295{b})"
        if gate == "NAND":  return f"({a}\u00b7{b})'"
        if gate == "NOR":   return f"({a}+{b})'"
        if gate == "NOT":   return f"{a}'"
        if gate == "XNOR":  return f"({a}\u2295{b})'"
        if gate == "EMPTY": return "?"
        return "?"
    e0 = sym(slots[0], "A", "B")
    e1 = sym(slots[1], "B", "C")
    e2 = sym(slots[2], e0, e1)
    e3 = sym(slots[3], e1, "D")
    e4 = sym(slots[4], e2, e3)
    return f"Y = {e4}"


# GPIO INPUT READER

def get_inputs():
    """Read all 4 switch inputs. Returns [A, B, C, D] as 0/1."""
    return [1 if GPIO.input(pin) == GPIO.LOW else 0 for pin in INPUT_PINS]


# RFID THREAD — 5 readers polled in background

slots     = ["EMPTY"] * NUM_SLOTS
rfid_lock = threading.Lock()

reset_event = threading.Event()

def rfid_thread():
    """
    Creates one SimpleMFRC522 per slot using its CS pin.
    Polls all 5 nonblocking — updates slots[] directly.
    """
    readers = []
    for cs in CS_PINS:
        try:
            r = SimpleMFRC522(dev=0, speed=1000000, pin_cs=cs, pin_rst=25)
            readers.append(r)
            print(f"[RFID] Reader on CS {cs} initialized")
        except Exception as e:
            print(f"[RFID] Failed to init reader on CS {cs}: {e}")
            readers.append(None)

    # Track last UID per slot for debounce
    last_uids = [None] * NUM_SLOTS

    while True:
        if reset_event.is_set():
            with rfid_lock:
                for i in range(NUM_SLOTS):
                    slots[i] = "EMPTY"

            last_uids = [None] * NUM_SLOTS
            reset_event.clear()
            print("[RESET] All slots cleared")

        for i, reader in enumerate(readers):
            if reader is None:
                continue
            try:
                uid = reader.read_no_block()
                if uid and uid != last_uids[i]:
                    last_uids[i] = uid
                    gate = rfid_gate_map.get(uid, "EMPTY")
                    with rfid_lock:
                        slots[i] = gate
                    if gate != "EMPTY":
                        print(f"[RFID] Slot {i+1} = {gate}  (UID {uid})")
                    else:
                        print(f"[RFID] Unknown UID on slot {i+1}: {uid}")
                        print(f"       Add:  {uid}: \"GATE_TYPE\"")
                elif not uid and last_uids[i] is not None:
                    # Tag removed — clear debounce so it can be re read
                    last_uids[i] = None
            except Exception as e:
                pass   # ignore transient SPI errors during polling
        time.sleep(0.05)


# PYGAME DISPLAY

SW, SH = 1920, 1080   # change to 1280, 720 for 720p display

pygame.init()
screen      = pygame.display.set_mode((SW, SH), pygame.FULLSCREEN)
pygame.display.set_caption("RFID Logic Gate System")
clock       = pygame.time.Clock()
font        = pygame.font.SysFont("Verdana",   17)
small_font  = pygame.font.SysFont("Verdana",   14)
header_font = pygame.font.SysFont("Verdana",   22, bold=True)
expr_font   = pygame.font.SysFont("dejavusans", 18, bold=True)

# Gate images
base_path   = os.path.dirname(os.path.abspath(__file__))
GATE_IMAGES = {}
for gate in ["AND", "OR", "XOR", "NAND", "NOR", "NOT", "XNOR"]:
    path = os.path.join(base_path, f"{gate}.png")
    try:
        if os.path.exists(path):
            raw  = pygame.image.load(path).convert_alpha()
            surf = pygame.Surface((120, 80))
            surf.fill((255, 255, 255))
            surf.blit(pygame.transform.smoothscale(raw, (120, 80)), (0, 0))
            GATE_IMAGES[gate] = surf
    except Exception as e:
        print(f"[IMG] Could not load {gate}.png: {e}")

GATE_COLORS = {
    "AND": (0,130,220), "OR": (220,100,0), "XOR": (140,0,220),
    "NAND": (220,50,50), "NOR": (50,180,100), "NOT": (180,180,180), "XNOR": (0,150,150)
}

GW, GH = 120, 80

GATE_POS = {
    0: (200, 140),
    1: (200, 440),
    2: (460, 240),
    3: (460, 500),
    4: (720, 360),
}

NODE_R = 14
INPUT_POS = {
    "A": (50, 165),
    "B": (50, 280),
    "C": (50, 545),
    "D": (50, 630),
}

PIN_TOP_Y = int(GH * 0.28)
PIN_BOT_Y = int(GH * 0.72)
PIN_OUT_Y = GH // 2
WIRE_W    = 3
BG_COL    = (18, 22, 34)


def gate_out_pos(idx):
    gx, gy = GATE_POS[idx]; return gx + GW, gy + PIN_OUT_Y

def gate_in_top(idx):
    gx, gy = GATE_POS[idx]; return gx, gy + PIN_TOP_Y

def gate_in_bot(idx):
    gx, gy = GATE_POS[idx]; return gx, gy + PIN_BOT_Y


def wire(p1, p2, val):
    col = (0, 210, 230) if val else (45, 55, 70)
    pygame.draw.line(screen, col, p1, p2, WIRE_W)


def draw_node(name, val, cx, cy):
    col = (0, 210, 230) if val else (60, 65, 80)
    pygame.draw.circle(screen, col, (cx, cy), NODE_R)
    pygame.draw.circle(screen, (140,145,160), (cx, cy), NODE_R, 2)
    v = small_font.render(str(val), True, (10,10,10) if val else (200,205,215))
    screen.blit(v, (cx - v.get_width()//2, cy - v.get_height()//2))
    lbl = small_font.render(name, True, (180,185,200))
    screen.blit(lbl, (cx - NODE_R - lbl.get_width() - 6, cy - lbl.get_height()//2))


def draw_gate_box(idx, gate_type):
    gx, gy = GATE_POS[idx]
    pygame.draw.rect(screen, (255,255,255), (gx, gy, GW, GH))
    if gate_type == "EMPTY":
        pygame.draw.rect(screen, (55,60,75), (gx,gy,GW,GH), 2, border_radius=8)
    else:
        pygame.draw.rect(screen, (220,220,220), (gx,gy,GW,GH), 2, border_radius=8)
    if gate_type not in ("EMPTY", None):
        if GATE_IMAGES.get(gate_type):
            screen.blit(GATE_IMAGES[gate_type], (gx, gy))
            pygame.draw.rect(screen, (220,220,220), (gx,gy,GW,GH), 2, border_radius=8)
        else:
            col = GATE_COLORS.get(gate_type, (100,100,100))
            pygame.draw.rect(screen, col, (gx,gy,GW,GH), border_radius=8)
            lbl = font.render(gate_type, True, (255,255,255))
            screen.blit(lbl, (gx+(GW-lbl.get_width())//2, gy+(GH-lbl.get_height())//2))
    n = small_font.render(f"S{idx+1}", True, (130,135,150))
    screen.blit(n, (gx+GW//2 - n.get_width()//2, gy+GH+4))


def draw_all(slots, inputs):
    """
    This function draws the entire screen.
    :param slots:
    :param inputs:
    :return:
    """
    screen.fill(BG_COL)

    out0, out1, out2, out3, out4 = eval_circuit(slots, inputs)
    a, b, c, d = inputs

    # Header
    screen.blit(header_font.render("RFID Logic Gate System", True, (0,220,220)), (20,12))
    screen.blit(expr_font.render(build_boolean_expr(slots), True, (255,210,0)), (20,44))
    screen.blit(small_font.render("ESC = exit", True, (80,85,100)), (20,76))

    # Input nodes
    for name, (nx, ny) in INPUT_POS.items():
        val = {"A":a,"B":b,"C":c,"D":d}[name]
        draw_node(name, val, nx, ny)

    # A -> S1 top
    ax, ay = INPUT_POS["A"]; t0x, t0y = gate_in_top(0)
    wire((ax+NODE_R, ay), (t0x, ay), a)
    wire((t0x, ay), (t0x, t0y), a)

    # B -> S1 bot + S2 top (shared)
    bx, by = INPUT_POS["B"]
    b0x, b0y = gate_in_bot(0); t1x, t1y = gate_in_top(1)
    jbx = b0x - 18
    wire((bx+NODE_R, by), (jbx, by), b)
    wire((jbx, by), (jbx, b0y), b); wire((jbx, b0y), (b0x, b0y), b)
    wire((jbx, by), (jbx, t1y), b); wire((jbx, t1y), (t1x, t1y), b)
    pygame.draw.circle(screen, (0,210,230) if b else (45,55,70), (jbx, by), 5)

    # C -> S2 bot
    cx2, cy2 = INPUT_POS["C"]; b1x, b1y = gate_in_bot(1)
    wire((cx2+NODE_R, cy2), (b1x, cy2), c)
    wire((b1x, cy2), (b1x, b1y), c)

    # D -> S4 bot
    dx, dy = INPUT_POS["D"]; b3x, b3y = gate_in_bot(3)
    wire((dx+NODE_R, dy), (b3x, dy), d)
    wire((b3x, dy), (b3x, b3y), d)

    # S1 out -> S3 top
    o0x, o0y = gate_out_pos(0); t2x, t2y = gate_in_top(2)
    mid0x = o0x + 20
    wire((o0x, o0y), (mid0x, o0y), out0)
    wire((mid0x, o0y), (mid0x, t2y), out0)
    wire((mid0x, t2y), (t2x, t2y), out0)

    # S2 out -> S3 bot + S4 top (shared)
    o1x, o1y = gate_out_pos(1)
    b2x, b2y = gate_in_bot(2); t3x, t3y = gate_in_top(3)
    mid1x = o1x + 50
    jsy = (b2y + t3y) // 2
    wire((o1x, o1y), (mid1x, o1y), out1)
    wire((mid1x, o1y), (mid1x, jsy), out1)
    wire((mid1x, jsy), (mid1x, b2y), out1); wire((mid1x, b2y), (b2x, b2y), out1)
    wire((mid1x, jsy), (mid1x, t3y), out1); wire((mid1x, t3y), (t3x, t3y), out1)
    pygame.draw.circle(screen, (0,210,230) if out1 else (45,55,70), (mid1x, o1y), 6)

    # S3 out -> S5 top
    o2x, o2y = gate_out_pos(2); t4x, t4y = gate_in_top(4)
    mid2x = o2x + 20
    wire((o2x, o2y), (mid2x, o2y), out2)
    wire((mid2x, o2y), (mid2x, t4y), out2)
    wire((mid2x, t4y), (t4x, t4y), out2)

    # S4 out -> S5 bot
    o3x, o3y = gate_out_pos(3); b4x, b4y = gate_in_bot(4)
    mid3x = o3x + 20
    wire((o3x, o3y), (mid3x, o3y), out3)
    wire((mid3x, o3y), (mid3x, b4y), out3)
    wire((mid3x, b4y), (b4x, b4y), out3)

    # Final output
    o4x, o4y = gate_out_pos(4)
    out_col = (0,220,80) if out4 else (200,60,60)
    pygame.draw.line(screen, out_col, (o4x, o4y), (o4x+70, o4y), WIRE_W)
    screen.blit(font.render("OUT", True, (130,135,150)), (o4x+74, o4y+20))
    pygame.draw.circle(screen, out_col, (o4x+110, o4y), NODE_R)
    v = small_font.render(str(out4), True, (10,10,10))
    screen.blit(v, (o4x+110-v.get_width()//2, o4y-v.get_height()//2))

    # Gate boxes
    for i in range(NUM_SLOTS):
        draw_gate_box(i, slots[i])

    # Truth table
    table  = get_truth_table(slots)
    tx, ty = 1020, 50
    headers = ["A","B","C","D","|","OUT"]
    col_xs  = [tx + i*46 for i in range(6)]
    col_xs[4] -= 6
    screen.blit(header_font.render("Truth Table", True, (0,220,220)), (tx, ty))
    ty += 36
    for ci, h in enumerate(headers):
        screen.blit(font.render(h, True, (0,210,230)), (col_xs[ci], ty))
    ty += 28

    active_row = tuple(inputs)
    for ri, row in enumerate(table):
        is_active = (row[:4] == active_row)
        if is_active:
            pygame.draw.rect(screen, (35,58,88),
                             (tx-8, ty+ri*24-3, 262, 22), border_radius=4)
            pygame.draw.rect(screen, (0,160,200),
                             (tx-8, ty+ri*24-3, 262, 22), 1, border_radius=4)
        for ci in range(6):
            if ci == 4:
                screen.blit(small_font.render("|", True, (70,75,90)),
                            (col_xs[4], ty+ri*24))
                continue
            val    = row[ci] if ci < 4 else row[4]
            x      = col_xs[ci] if ci < 4 else col_xs[5]
            is_out = (ci == 5)
            if is_active:
                col = (0,235,255) if (is_out and val==1) else (255,255,255)
            else:
                col = (0,210,230) if (is_out and val==1) else (170,175,185)
            screen.blit(small_font.render(str(val), True, col), (x, ty+ri*24))


# MAIN

def main():
    # Setup switch GPIO pins
    GPIO.setmode(GPIO.BCM)
    GPIO.setwarnings(False)
    for pin in INPUT_PINS:
        GPIO.setup(pin, GPIO.IN, pull_up_down=GPIO.PUD_UP)

    GPIO.setup(RESET_PIN, GPIO.IN, pull_up_down=GPIO.PUD_DOWN)

    # Start RFID polling thread
    t = threading.Thread(target=rfid_thread, daemon=True)
    t.start()

    running = True

    try:
        while running:
            inputs = get_inputs()

            if GPIO.input(RESET_PIN) == GPIO.HIGH:
                reset_event.set()
                time.sleep(0.25)  # simple debounce delay

            with rfid_lock:
                current_slots = slots[:]

            draw_all(current_slots, inputs)
            pygame.display.flip()
            clock.tick(30)

            for event in pygame.event.get():
                if event.type == pygame.QUIT:
                    running = False
                if event.type == pygame.KEYDOWN:
                    if event.key == pygame.K_ESCAPE:
                        running = False

    finally:
        GPIO.cleanup()
        pygame.quit()


if __name__ == "__main__":
    main()

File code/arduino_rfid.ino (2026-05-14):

/*
THIS FILE IS INTERNAL ONLY, DO NOT ADD THIS TO GITHUB

RFID MULTI READER — Arduino Mega
5 RC522 readers, sends gate assignments to Pi over Serial

Wiring:
   All readers share: MOSI->51, MISO->50, SCK->52, RST->44

CHECK ALL THESE FPR ACCURACY
   Reader 1 CS -> Pin 49 
   Reader 2 CS -> Pin 53
   Reader 3 CS -> Pin 38
   Reader 4 CS -> Pin 46
   Reader 5 CS -> Pin 45

   All readers: 3.3V -> 3.3V, GND -> GND
*/

#include <SPI.h>
#include <MFRC522.h>

#define RST_PIN  44
#define NUM_READERS 5

// CS pins for each reader 38 39 40 43 49 {49, 53, 38, 46, 45};
const int CS_PINS[NUM_READERS] = {38, 40, 39, 43, 49};

// Create reader instances
MFRC522 readers[NUM_READERS] = {
    MFRC522(CS_PINS[0], RST_PIN),
    MFRC522(CS_PINS[1], RST_PIN),
    MFRC522(CS_PINS[2], RST_PIN),
    MFRC522(CS_PINS[3], RST_PIN),
    MFRC522(CS_PINS[4], RST_PIN)
};

// UID to gate type mapping
String getGate(String uid) {
    if (uid == "346BC201") return "AND";
    if (uid == "CAB31406") return "AND";
    if (uid == "47241DA3") return "AND";
    if (uid == "E7AB99A2")  return "OR";
    if (uid == "A4E700E5")  return "OR";
    if (uid == "1A16F8E1")  return "OR";
    if (uid == "271E9C04")  return "XOR";
    if (uid == "E71837A2")  return "XOR";
    if (uid == "E4F0FBE5")  return "NAND";
    if (uid == "C79213A2")  return "NAND";
    if (uid == "E76CB4A2")  return "XNOR";
    if (uid == "66971306")  return "XNOR";
    if (uid == "E77228A2")  return "NOR";
    if (uid == "05812C1F")  return "NOR";
    return "EMPTY";
}

// Current gate in each slot
String slots[NUM_READERS] = {
    "EMPTY", "EMPTY", "EMPTY", "EMPTY", "EMPTY"
};

// Track last UID per slot for debounce
String lastUIDs[NUM_READERS] = {"", "", "", "", ""};

// SETUP
void setup() {
    Serial.begin(9600);   // USB Serial to Pi

    SPI.begin();

    // Init all readers
    for (int i = 0; i < NUM_READERS; i++) {
        readers[i].PCD_Init();
        delay(50);

        // Version check
        byte ver = readers[i].PCD_ReadRegister(MFRC522::VersionReg);
        Serial.print("[RFID] Reader ");
        Serial.print(i + 1);
        Serial.print(" CS=");
        Serial.print(CS_PINS[i]);
        Serial.print(" version=");
        Serial.print(ver, HEX);
        if (ver == 0x91 || ver == 0x92 || ver == 0x82 || ver == 0x88 || ver == 0xB2) {
            Serial.println(" OK");
        } else {
            Serial.println(" CHECK WIRING");
        }
    }

    Serial.println("[READY]");
    sendSlots();   // send initial empty state to Pi
}


// Build UID string from card serial
String getUID(MFRC522 &reader) {
    String uid = "";
    for (byte i = 0; i < reader.uid.size; i++) {
        if (reader.uid.uidByte[i] < 0x10) uid += "0";
        uid += String(reader.uid.uidByte[i], HEX);
    }
    uid.toUpperCase();
    return uid;
}

// Send all slot states to Pi
// Format: "S1:AND,S2:OR,S3:EMPTY,S4:NAND,S5:XNOR\n"
void sendSlots() {
    String msg = "";
    for (int i = 0; i < NUM_READERS; i++) {
        msg += "S" + String(i + 1) + ":" + slots[i];
        if (i < NUM_READERS - 1) msg += ",";
    }
    Serial.println(msg);
}

// MAIN LOOP

void loop() {
    bool changed = false;

    for (int i = 0; i < NUM_READERS; i++) {
        if (readers[i].PICC_IsNewCardPresent() &&
            readers[i].PICC_ReadCardSerial()) {

            String uid  = getUID(readers[i]);
            String gate = getGate(uid);

            // Only update if this is a different tag than last time
            if (uid != lastUIDs[i]) {
                lastUIDs[i] = uid;   
                slots[i]    = gate;
                changed     = true;

                if (gate != "EMPTY") {
                    Serial.print("[RFID] Slot ");
                    Serial.print(i + 1);
                    Serial.print(" = ");
                    Serial.print(gate);
                    Serial.print("  UID: ");
                    Serial.println(uid);
                } else {
                    Serial.print("[RFID] Unknown UID slot ");
                    Serial.print(i + 1);
                    Serial.print(": ");
                    Serial.println(uid);
                    Serial.println("       Add to getGate()");
                }
            }

            readers[i].PICC_HaltA();
            readers[i].PCD_StopCrypto1();
        }
        
        delay(10);
    }

    if (changed) {
        sendSlots();
    }

    delay(50);

    // Reset button, possibly add extra rfid tag as a reset
    /*
    if (digitalRead(2) == LOW) {
    for (int i = 0; i < NUM_READERS; i++) {
        lastUIDs[i] = "";
        slots[i] = "EMPTY";
    }
    changed = true;
    Serial.println("[RESET] All slots cleared");
    }
    */
}

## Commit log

2026-05-14 3rd Party Pico 2
    These files are 3rd party boards with more GPIO and used for completely custom PCB designs
2026-05-14 Standard Pico 2
    These files are the standard Pico 2 from Raspberry Pi.
2026-05-14 Update README with Version 2 details
    Added information about Version 2 of the PCB design.
2026-05-14 v1 - Arduino Readers
2026-05-14 v1 - Raspberry Pi Only
